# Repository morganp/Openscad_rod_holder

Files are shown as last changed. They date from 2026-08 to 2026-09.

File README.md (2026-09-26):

# openGrid Rod Holder

A deep, narrow pot that snaps onto an [openGrid](https://www.opengrid.world/)
board and keeps thin steel rod sorted by diameter. Built for 0.5 mm and 0.8 mm
hinge pin stock, but every dimension is parametric.

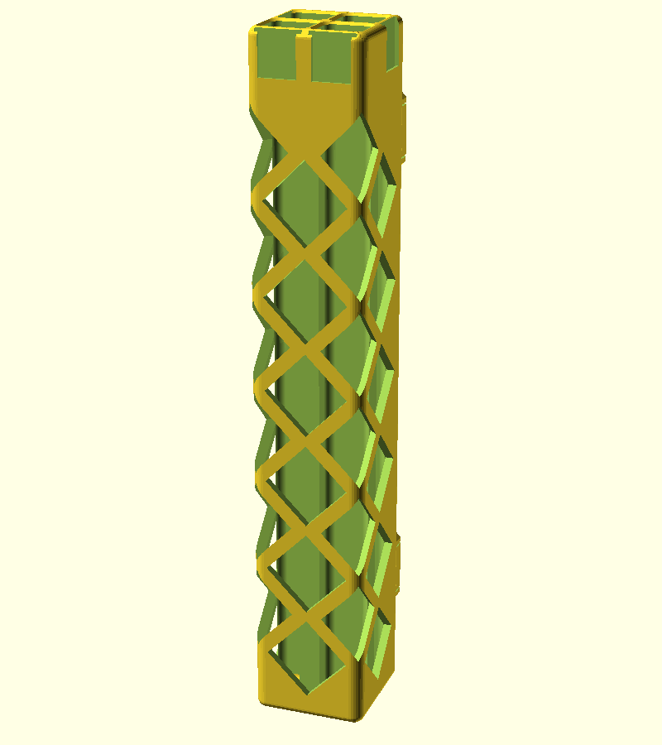
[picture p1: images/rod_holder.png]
Rod holder


- 1 grid cell square, 6 cells tall: 27.6 x 27.6 x 167.6 mm
- 4 compartments in a 2 x 2 grid, 11.0 x 10.5 mm, 165.6 mm deep, rounded inside
- A lattice of diamond windows up the outer walls, wrapping round the front
  corners, so short offcuts at the bottom can be seen
- Card label pocket for every compartment: front row on the front, back row on
  the sides
- Mounts on 2 snaps: one at the top, one at the bottom
- Tiles in both directions, so a wall of them lines up

Sized for 300 mm rod: the pot holds the bottom 166 mm and the rest stands
proud, so a full length rod is easy to grab.

Version 1 was 2 cells wide with 4 compartments in a single row. That is still
one setting away, see [v1 layout](#v1-layout).

## Requirements

The openGrid connector geometry lives in a separate library so other openGrid
projects can share it:

```sh
git clone https://github.com/morganp/openscad-opengrid.git \
  ~/Documents/OpenSCAD/libraries/opengrid
```

Then open `rod_holder.scad` in OpenSCAD.

Or open it in the browser with no install, library included:
[rod_holder.scad in the web OpenSCAD GUI](https://lizard-spock.co.uk/openscad-gui/?github=morganp/Openscad_rod_holder/rod_holder.scad).
The `// @github: morganp/openscad-opengrid` comment above the `include` tells
the web GUI where to fetch the library from; desktop OpenSCAD ignores it.

---

## Tiling

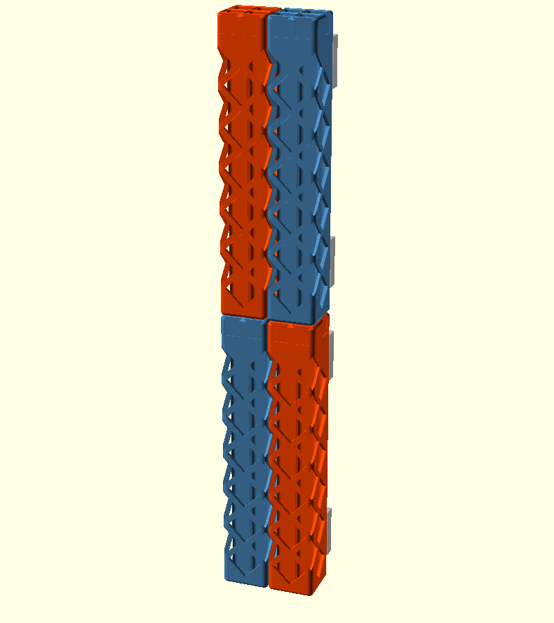
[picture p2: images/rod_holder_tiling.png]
Tiling


*Four holders in a 2 x 2 block, with the board cells their snaps sit in shown behind.*

The outer size is a whole number of grid cells **less `tile_clearance`**, taken
off the outside so the snaps stay put. At the defaults the holder is 27.6 x
167.6 mm and sits on a 28 x 168 mm footprint, which is 1 x 6 cells. It sits flush
beside any other holder or bin built to whole grid cells, and six-cell holders
stack flush above each other. Butt them up
against each other and every snap still lands on the 28 mm grid, with 0.4 mm of
air between neighbours so they do not rub.

Vertical tiling is what `height_mode` is for:

| `height_mode` | Height | Bore | Tiles vertically |
|---|---|---|---|
| `"grid"` (default) | Rounded up to a whole number of cells, 167.6 | 165.6 | Yes |
| `"exact"` | `bore_depth + floor_thickness`, 160 | 158 | No |

In `"grid"` mode `bore_depth` is a **minimum**. The height rounds up to the next
whole cell and the spare goes into the bore, so asking for 158 mm gets you
165.6 mm rather than 8 mm of dead plastic in the base. Use `"exact"` if you
want the bore depth you asked for and do not care about stacking.

---

## Layout

The pot's back wall *is* the mounting plate, so there is no separate bracket.
Snaps sit in the top and bottom rows only, one per column of grid cells.

Compartments form a grid: `compartments` across and `compartment_rows` front to
back. The depth comes from `pot_depth`:

| `pot_depth` | Depth | Compartments |
|---|---|---|
| `-1` (default) | Matches the width, 27.6 | Share the space behind the front wall, 10.5 deep each |
| `0` | `back_plate + rows * depth + dividers + wall` | `compartment_depth` deep, or square if that is 0 |
| any other value | That value | Share the space behind the front wall |

Snap centres have to land on the 28 mm grid and need 14 mm of clearance to any
plate edge, so the rows are pushed as far apart as the height allows and the
pair is centred:

```
snap_span = floor((pot_h - 28) / 28) * 28
snap_z0   = (pot_h - snap_span) / 2
```

At 167.6 mm tall that puts the rows 112 mm apart at z = 27.8 and z = 139.8.
Change `bore_depth` and they move to suit.

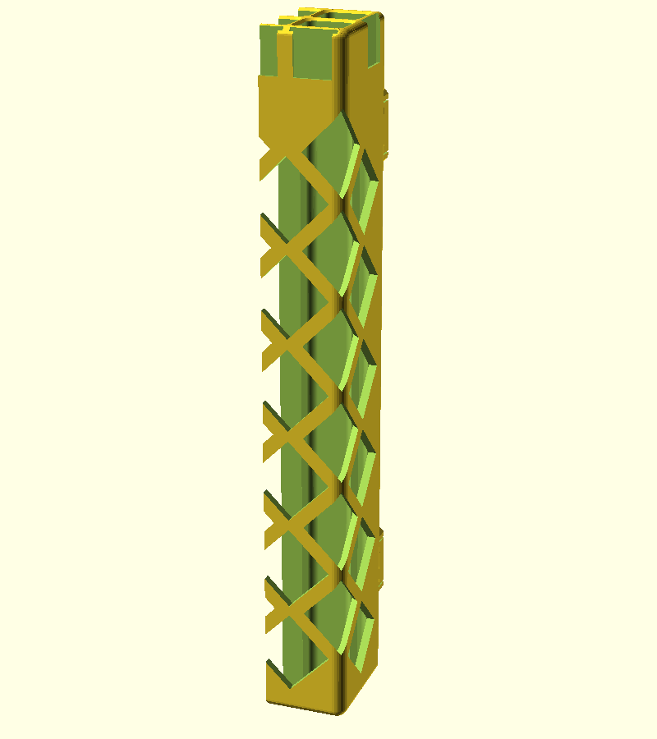
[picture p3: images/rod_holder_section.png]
Section


*Cut down the middle of the left column: the front and back bores, the floor, the diamond windows cut through the front wall, and the back plate the snaps hang off.*

---

## Windows

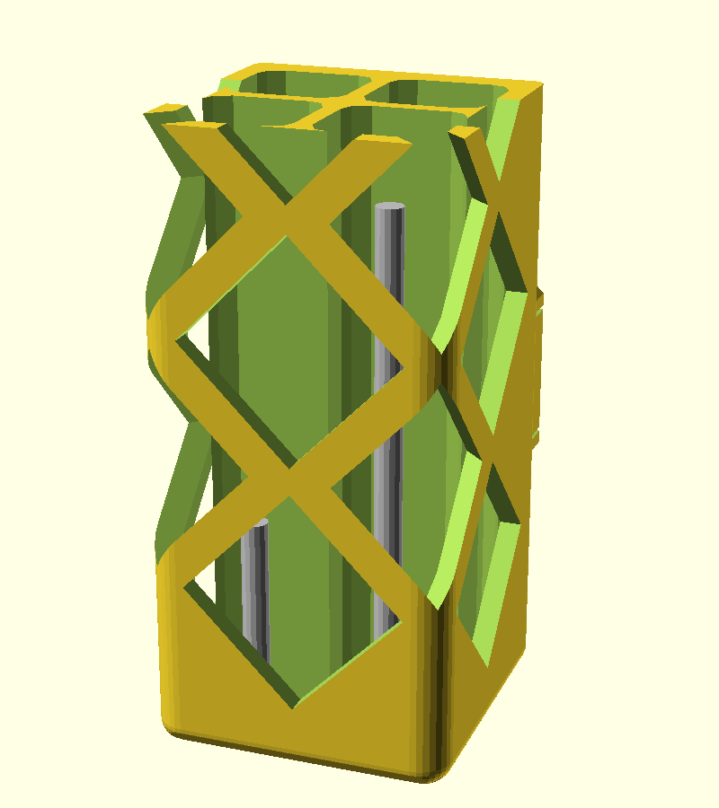
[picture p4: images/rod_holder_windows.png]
Windows


*The bottom of a holder from the front corner, with short offcuts standing in
the compartments. Offcuts drawn thicker than real rod so they show up.*

Rod gets used up from the top, so the pieces that get forgotten are the short
offcuts sitting at the bottom of a 166 mm deep bore. A lattice of diamond
windows runs up the outer walls so you can see them without tipping the holder
out.

The diamonds sit in alternating rows:

- **Row A** puts one diamond in the middle of each face. On the front it is
  centred on the grid cell, so on a 1 cell holder it spans both compartment
  columns. On each side it is centred between the back plate and the front
  wall, so it spans both compartment rows.
- **Row B**, half a pitch higher, puts a diamond on each front vertical edge.
  It wraps round the corner, half on the front and half on the side, and opens
  up the front corner of the compartment behind it. It is cut as one prism
  running in along the corner's 45 degree bisector, so the outline runs
  continuously over the rounded edge and each face still shows a 45 degree
  half diamond. Cutting a half diamond straight into each face instead leaves
  pinched nubs where the webs cross the rounded corner. On holders wider than one
  cell, row B also has a full diamond on the front at every cell boundary.
- The back edges and the back plate stay solid. That is where the snaps are.

At the defaults the diamonds are 20.2 mm across, 45 degree squares, with a
2.4 mm web between neighbours. There are 12 rows, 22.6 mm apart for rows of
the same kind: 6 A rows and 6 B rows, from 6 mm above the bottom to just below
the card pockets. So each side face has 6 full diamonds and 6 half diamonds
round the corner, and the front has 6 full diamonds and 12 corner halves.

`diamond_size = 0` makes the diamonds as big as the faces allow, and a larger
value is clamped to that with a note in the console. The spacing follows from
the size and `diamond_web`: rows of the same kind are spaced so their tips are
a web apart, and an A and a B diamond are a web apart across the diagonal.

The windows only cut the outer walls. Where a row A diamond crosses the end of
a divider it takes the wall off the end of the divider, but the divider stays
joined to the back plate, to the other divider, and to the outer wall at every
row B height, so the part is still one solid. At the wrapped corners the cut
also clears the rounded inside corner of the compartment, which would
otherwise be left as a thin free standing sliver in the middle of the opening.

**Why the windows start above the floor.** The lowest diamond tip is
`window_start` (4 mm) above the floor. A rod standing in a compartment rests its
bottom end on the floor behind solid wall, so to lean out of a window it would
have to be lifted over that band first. Gravity keeps it seated, and a rod
leaning against a window can only poke its *top* end out, which slides it
upwards, not out. Offcuts shorter than the compartment is wide can lie flat on
the floor, below the windows. The holder can still lose short pieces if it is
knocked off the wall or turned upside down.

**Tiling hides the side windows.** Holders butted up to each other cover each
other's side faces. The front diamonds and the front halves of the corner
diamonds still show all four compartments' front corners; the back row is only
fully visible from a free side (the end of a row), a one cell gap, or the top.

**Printing.** Front face down, the front diamonds are holes in the first
layers, and every edge of the side diamonds runs at 45 degrees, so there are no
bridges and no support.

`window_style = "slot"` gives the earlier ladder of narrow slots, one column per
compartment, and `"none"` leaves the walls solid.

---

## Rounding

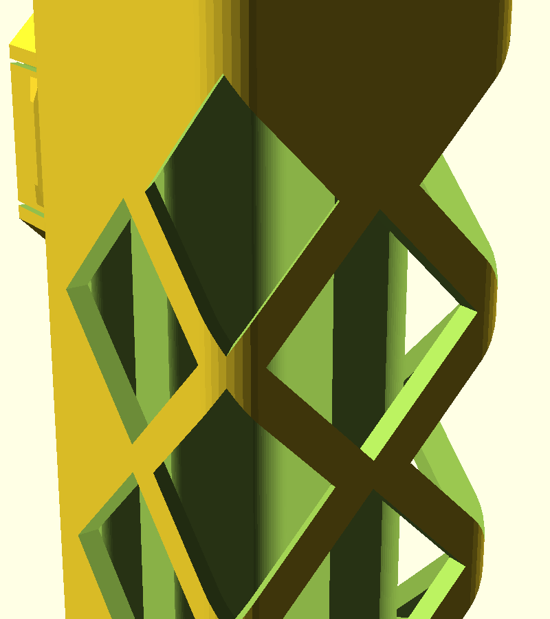
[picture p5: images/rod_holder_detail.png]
Detail


*The top of the pot: rounded outer edges, the lead-in at each mouth, front card
pockets for the front row, a side pocket for the back row, and the top of the
diamond lattice with a corner diamond wrapping the front edge.*

Outside, the two front vertical edges are rounded by `outer_round`, the top and
bottom edges by `end_round`. Inside, the compartment corners are rounded by
`inner_round` and there is a fillet where the walls meet the floor.

Two edges cannot simply be rounded, for reasons worth knowing before you change
the values:

**The back edges.** Rounding the back face perimeter eats into the flat area the
snaps root into. Each snap reaches 12.4 mm from its centre and a one cell pot
is 13.8 mm from centre to side, so anything above 1.4 mm would undercut them. `back_round` defaults
to 1.2 and is checked by an assert.

**The front face perimeter.** The front face is the bed when printing. A fillet
tangent to the bed leaves the first layers as a near-horizontal overhang, which
prints badly. So the rounding is cut back to 45 degrees where it runs into that
face, by `front_chamfer`. This catches the side edges and the top and bottom
edges in one operation. Set `front_chamfer = 0` for an unbroken round, and print
with support.

The mouth lead-in grows every compartment sideways and backwards, so two
neighbours eat into the divider between them from both sides. It is clamped to
leave at least 0.4 mm on top of each divider, which means the effective lead-in
can be smaller than `mouth_chamfer` asks for. It never grows into an outer wall
that carries a card pocket.

---

## Card labels

Every compartment gets a pocket in an outer wall that holds a slip of card
behind a window. Cards drop in from the top of the pot and pull straight back
out, so relabelling means writing a new slip rather than reprinting the holder.

- Front row compartments are labelled on the front face.
- Rows behind that are labelled on the side wall they touch: the left back
  compartment on the left side, the right one on the right. A single column
  uses the left side.
- A compartment that touches no outer wall (a middle column of three or more,
  behind the front row) cannot be labelled, and OpenSCAD echoes a note.

At the defaults the front cards are 11.0 x 12 mm with a 9.0 x 11 mm window, the
side cards 10.5 x 12 mm with an 8.5 x 11 mm window, all in 0.7 mm slots. Cut a
strip of 300 gsm card, or fold ordinary paper double.

Set `label_mode = "engraved"` to cut fixed text into the same faces instead, or
`"none"` to leave it plain. `labels` runs front row left to right as mounted,
then the next row back, left to right.

---

## Parameters

### openGrid

| Parameter | Default | Description |
|---|---|---|
| `grid_cols` | `1` | How many grid cells wide |
| `lite_board` | `false` | `true` for a 4.0 mm Lite board, `false` for a 6.8 mm Full board |
| `snap_clearance` | `0` | Raise to 0.05 to 0.1 if the snaps print tight |
| `tile_clearance` | `0.4` | Gap left between neighbouring holders. Taken off the outside, the snaps stay on the grid |
| `height_mode` | `"grid"` | `"grid"` rounds the height to whole cells so holders tile vertically. `"exact"` gives exactly `bore_depth + floor_thickness` |

### Pot

| Parameter | Default | Description |
|---|---|---|
| `bore_depth` | `158` | Usable compartment depth. A minimum in `"grid"` mode |
| `compartments` | `2` | Number of compartments across the width |
| `compartment_rows` | `2` | Number of compartment rows, front to back |
| `pot_depth` | `-1` | `-1` matches the width, `0` sizes from `compartment_depth`, any other value is the depth |
| `wall` | `2.0` | Front and side wall thickness |
| `divider` | `1.6` | Thickness of the walls between compartments |
| `back_plate` | `3.0` | Back plate thickness, this is what the snaps hang off |
| `floor_thickness` | `2.0` | Material under the compartments |
| `compartment_depth` | `0` | Front to back size, used only when `pot_depth = 0`. `0` makes the compartments square |
| `mouth_chamfer` | `1.0` | Lead-in at the mouth. Never opens into a wall with a card pocket. Clamped so it cannot eat the divider tops away |

Compartment width is whatever is left over:

```
comp_w = (grid_cols * 28 - tile_clearance - 2 * wall
          - (compartments - 1) * divider) / compartments
```

which gives 11.0 mm at the defaults, and the depth is shared the same way
behind the front wall, 10.5 mm.

### Windows

| Parameter | Default | Description |
|---|---|---|
| `window_style` | `"diamond"` | `"diamond"` lattice, `"slot"` ladders, or `"none"` |
| `window_sides` | `true` | Windows in the side walls |
| `window_front` | `true` | Windows in the front wall |
| `window_start` | `4` | Solid band above the floor before the first window |
| `window_zone` | `0` | Height of the windowed region above `window_start`. `0` runs up to just below the labels |
| `diamond_size` | `0` | Diamond diagonal. `0` is as big as the faces allow, larger values are clamped to that |
| `diamond_web` | `2.4` | Narrowest web between diamonds, and between diamonds and the labels. At least 1.6 |
| `diamond_corners` | `true` | Diamonds wrapped round the two front vertical edges |
| `window_width` | `4` | Slot style only. Slot width, clamped to the flat part of the compartment wall |
| `window_height` | `10` | Slot style only. Height of each slot, and the bridge over it when printing |
| `window_bar` | `4` | Slot style only. Solid rung between slots |

### Rounding

| Parameter | Default | Description |
|---|---|---|
| `outer_round` | `3.0` | Radius on the two front vertical edges, the ones you grip |
| `back_round` | `1.2` | Radius on the two back vertical edges. Capped by the snap footprint, see above |
| `end_round` | `2.0` | Radius on the top and bottom outer edges |
| `front_chamfer` | `1.6` | 45 degree relief where the rounding meets the front face, so it prints off the bed. `0` gives an unbroken round |
| `inner_round` | `2.0` | Radius on the inside vertical corners of each compartment |
| `floor_round` | `2.0` | Radius where the compartment walls meet the floor |

### Labels

| Parameter | Default | Description |
|---|---|---|
| `label_mode` | `"card"` | `"card"`, `"engraved"` or `"none"` |
| `card_height` | `12` | Height of the card pocket. Width follows the compartment |
| `card_thickness` | `0.7` | Thickness of card the slot takes |
| `card_lip` | `0.6` | Front frame that stops the card falling out |
| `card_lip_margin` | `1.0` | How far that frame overlaps the card at the sides and bottom |
| `card_side_gap` | `0.8` | Gap each side of the card. Twice this is the rib between neighbouring pockets, so keep it near half the divider thickness |
| `labels` | `["0.5", "0.8", "1.0", "1.5"]` | Engraved mode only. Front row left to right as mounted, then the next row back |
| `label_size` | `5` | Engraved glyph height |
| `label_depth` | `0.6` | Engraving depth |
| `label_inset` | `10` | Engraved mode only, distance from the top down to the middle of the text |

### Output

| Parameter | Default | Description |
|---|---|---|
| `layout` | `"assembled"` | `"assembled"` shows it as mounted, `"print"` lays it out for the bed |
| `show_board` | `false` | Draw the board cells behind it, preview only |

---

## Printing

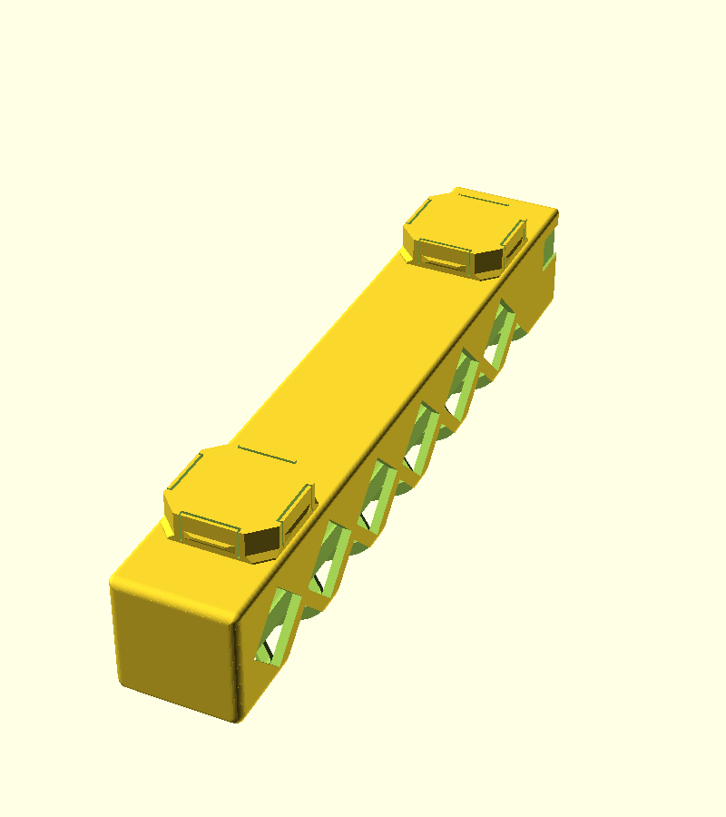
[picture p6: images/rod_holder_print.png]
Print layout


Set `layout = "print"`. That lays the pot **front face down** with the snaps
pointing up, which is the orientation this part wants:

- every snap overhang is 45 degrees or shallower, so no support is needed
- the front card pocket frames are on the bed and come out crisp, and the roof
  of each pocket is a short flat bridge between two edges
- the side diamonds have 45 degree edges all round, so they need no bridges
- the side card pockets are holes in vertical walls, each topped by a 10 to
  11 mm flat bridge
- the compartment bores run horizontally and need no bridging

Following the [openGrid printing guide](https://www.opengrid.world/guides/printing/):

- 0.4 mm nozzle, 0.2 mm layer height
- PLA or PETG, not flexibles
- At least 3 perimeters, this part hangs off a wall
- 15% infill or more
- Do not use a draft or fast profile, it will ruin the snap tolerances

Bed needs to fit 167.6 x 27.6 mm, 34.4 mm tall with the snaps. About 48 cm3 of
material at the defaults.

**Print one snap first.** Run the library's tile and snap examples and check the
fit by hand before committing to a 168 mm part.

---

## Verifying the fit

`mountfit_check.scad` intersects the finished holder with the board cells its
snaps sit in. A snap that fits has zero overlap with the board, so exporting
that intersection should give a zero volume solid:

```sh
openscad --export-format=binstl -o mountfit.stl mountfit_check.scad
```

This currently comes out at 0 mm3, so the snaps clear their cells everywhere at
rest.

---

## v1 layout

The version 1 holder, 2 cells wide with 4 compartments in one row and no
windows, is these settings:

```sh
openscad -D grid_cols=2 -D compartments=4 -D compartment_rows=1 -D pot_depth=0 \
         -D bore_depth=150 -D window_style=\"none\" \
         -o rod_holder_v1.stl rod_holder.scad
```

That produces the same solid as v1.2.0, checked by volume (80.5 cm3) and
triangle count. Leave the windows on to get a v1 shape with windows.

---

## Files

```
rod_holder.scad        -- the model
mountfit_check.scad    -- snap-to-board interference check
section_preview.scad   -- cutaway used for the README image
tiling_preview.scad    -- 2 x 2 block used for the README image
windows_preview.scad   -- corner view with offcuts, used for the README image
images/                -- rendered previews
```

## Credit

openGrid is a wall and desk mounting system by **David D**, CC BY 4.0:
<https://www.printables.com/model/1214361-opengrid-walldesk-mounting-framework-and-ecosystem>

Connector geometry comes from
[openscad-opengrid](https://github.com/morganp/openscad-opengrid).

## Versioning

[Semantic Versioning 2.0.0](https://semver.org). See [CHANGELOG.md](CHANGELOG.md).

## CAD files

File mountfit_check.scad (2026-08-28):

// mountfit_check.scad -- verification, not part of the model.
// A snap that fits its cell has zero overlap with the board, so exporting this
// intersection should come out as an empty or zero volume solid.
use <rod_holder.scad>

intersection() {
    board_cells();
    rod_holder();
}

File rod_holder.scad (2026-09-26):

/*
 * rod_holder.scad -- openGrid mounted pot for thin steel rods
 *
 * A deep, narrow pot that snaps onto an openGrid board and keeps hinge pin
 * stock sorted by diameter. Sized around 0.5 mm and 0.8 mm steel rod, but every
 * dimension is parametric.
 *
 * Version 2.0.0: one grid cell square, four compartments in a 2 x 2 grid, and
 * a lattice of diamond windows in the outer walls so short offcuts at the
 * bottom can be seen.
 *
 * Requires: https://github.com/morganp/openscad-opengrid
 *   git clone .../openscad-opengrid ~/Documents/OpenSCAD/libraries/opengrid
 *
 * Coordinates: the openGrid board face is the y = 0 plane. Snaps reach back into
 * the board at y < 0, the pot stands off the wall at y > 0, and z = 0 is the
 * bottom of the pot.
 *
 * Holders tile. Width is a whole number of grid cells less tile_clearance, and
 * with height_mode = "grid" the height is too, so a row or a column of these
 * sits side by side on the board with every snap still on the 28 mm grid.
 */

// @github: morganp/openscad-opengrid
include <opengrid/opengrid.scad>

/* [openGrid] */
// how many grid cells wide the holder is
grid_cols = 1;          // [1:6]
// true for a 4.0 mm Lite board, false for a 6.8 mm Full board
lite_board = false;
// raise if the snaps print tight
snap_clearance = 0;     // [0:0.01:0.2]
// gap left between neighbouring holders so they do not rub. Taken off the
// outside of the pot, the snaps stay on the grid
tile_clearance = 0.4;   // [0:0.1:2]
// exact makes the pot bore_depth + floor tall. grid rounds the height up to a
// whole number of cells so holders also tile vertically, deepening the bore
height_mode = "grid";   // [exact, grid]

/* [Pot] */
// usable depth of each rod compartment. With height_mode = "grid" this is a
// minimum and the bore gets deeper to reach the next whole cell
bore_depth = 158;       // [20:1:300]
// number of compartments across the width
compartments = 2;       // [1:8]
// number of compartment rows, front to back
compartment_rows = 2;   // [1:4]
// overall depth from the board face to the front face. -1 matches the width,
// so a 1 cell holder is square. 0 sizes it from compartment_depth instead
pot_depth = -1;
// front and side wall thickness
wall = 2.0;
// thickness of the walls between compartments
divider = 1.6;
// back plate thickness, this is what the snaps hang off
back_plate = 3.0;
// thickness under the compartments
floor_thickness = 2.0;
// compartment size front to back, used only when pot_depth = 0. 0 makes them
// square
compartment_depth = 0;
// Lead in at the mouth of each compartment. Clamped so it cannot eat the tops
// of the dividers away, so the effective value may be smaller than this
mouth_chamfer = 1.0;

/* [Windows] */
// diamond cuts a lattice of diamonds through the outer walls, slot a ladder of
// narrow slots per compartment, none leaves the walls solid
window_style = "diamond";  // [diamond, slot, none]
// windows in the side walls
window_sides = true;
// windows in the front wall
window_front = true;
// solid band above the floor before the first window. Keeps the bottom end of
// a standing rod behind a wall, so it cannot slide out of a window
window_start = 4;
// height of the windowed region above window_start. 0 runs the windows up to
// just below the labels
window_zone = 0;

// -- diamond style --
// Diagonal of each diamond. 0 makes them as big as the faces allow, so the
// diamond on a face spans every compartment column behind it. Clamped to that
// size if set larger
diamond_size = 0;
// narrowest solid web left between neighbouring diamonds, and between the
// diamonds and the back plate or labels
diamond_web = 2.4;
// diamonds centred on the two front vertical edges, wrapping round the corner
// so half shows on the front and half on the side
diamond_corners = true;

// -- slot style --
// slot width. Clamped to the flat part of the compartment wall
window_width = 4;
// height of each slot
window_height = 10;
// solid rung left between slots
window_bar = 4;

/* [Rounding] */
// radius on the two front vertical edges, the ones you actually grip
outer_round = 3.0;
// radius on the two back vertical edges. Kept small: the back face has to stay
// flat out to the edge of the snaps, which reach 12.4 mm from each snap centre
back_round = 1.2;
// radius on the top and bottom outer edges
end_round = 2.0;
// 45 degree relief around the front face. The front face is the bed when
// printing, and a fillet tangent to the bed starts as a near horizontal
// overhang, so the rounding is cut back to 45 degrees where it meets that face.
// Set to 0 for an unbroken round, and print with support
front_chamfer = 1.6;
// radius on the inside vertical corners of each compartment
inner_round = 2.0;
// radius where the compartment walls meet the floor
floor_round = 2.0;

/* [Labels] */
// card holds a slip of card behind a window, engraved cuts the text into the
// outer face, none leaves it plain. Front row labels go on the front face,
// rows behind it are labelled on the side wall they touch
label_mode = "card";    // [card, engraved, none]

// -- card mode --
// height of the card pocket. Width follows the compartment
card_height = 12;
// thickness of card the pocket takes. 0.7 suits folded paper or 300 gsm card
card_thickness = 0.7;
// front frame that stops the card falling out
card_lip = 0.6;
// how far that frame overlaps the card at the sides and bottom
card_lip_margin = 1.0;
// gap each side of the card. Twice this is the rib left between neighbouring
// pockets, so do not take it below about half the divider thickness
card_side_gap = 0.8;

// -- engraved mode --
// one label per compartment, "" for none. Front row left to right as mounted,
// then the next row back, left to right. Extras are ignored
labels = ["0.5", "0.8", "1.0", "1.5"];
label_size = 5;
label_depth = 0.6;
// distance from the top of the pot down to the middle of the label
label_inset = 10;

/* [Output] */
// assembled shows it as mounted, print lays it front face down on the bed
layout = "assembled";   // [assembled, print]
// draw a piece of board behind it, preview only
show_board = false;

/* [Hidden] */
$fn = 64;
EPS = 0.01;

// ---------------------------------------------------------------------------
// Derived dimensions
// ---------------------------------------------------------------------------

// Outer size is a whole number of cells less the tiling gap, so neighbouring
// holders leave tile_clearance between them while their snaps stay 28 mm apart.
pot_w    = og_span(grid_cols) - tile_clearance;         // 27.6 for 1 cell
grid_h   = ceil((bore_depth + floor_thickness) / OG_PITCH) * OG_PITCH;
pot_h    = height_mode == "grid" ? grid_h - tile_clearance
                                 : bore_depth + floor_thickness;
bore     = pot_h - floor_thickness;             // 165.6 in grid mode
inner_w  = pot_w - 2 * wall;
comp_w   = (inner_w - (compartments - 1) * divider) / compartments;

// Depth either comes from the compartments (pot_depth = 0) or is fixed and the
// compartments share out whatever is left behind the front wall.
rows_gaps = (compartment_rows - 1) * divider;
pot_d    = pot_depth < 0 ? pot_w
         : pot_depth > 0 ? pot_depth
         : back_plate + compartment_rows * (compartment_depth > 0 ? compartment_depth : comp_w)
           + rows_gaps + wall;
comp_d   = (pot_d - back_plate - wall - rows_gaps) / compartment_rows;

// The mouth lead in grows every compartment sideways, so two neighbours eat
// into the divider between them from both sides. Clamp it so the top of a
// divider keeps at least divider_top_min of material rather than coming to a
// knife edge, or vanishing entirely when 2 * mouth_chamfer exceeds divider.
divider_top_min = 0.4;
mouth = compartments > 1 || compartment_rows > 1
        ? min(mouth_chamfer, max(0, (divider - divider_top_min) / 2))
        : mouth_chamfer;

// Snap rows sit on the 28 mm grid and need 14 mm of clearance to a plate edge,
// so push them as far apart as the height allows and centre the pair.
snap_span = floor((pot_h - OG_PITCH) / OG_PITCH) * OG_PITCH;
snap_z0   = (pot_h - snap_span) / 2;
snap_zs   = snap_span > 0 ? [snap_z0, pot_h - snap_z0] : [pot_h / 2];
snap_xs   = [ for (c = [0 : grid_cols - 1]) (c - (grid_cols - 1) / 2) * OG_PITCH ];
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

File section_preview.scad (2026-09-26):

// section_preview.scad -- cutaway used for the README image.
// Not part of the model, it just slices rod_holder() down the middle of the
// left hand column so the front and back bores, the floor, the diamond windows and the
// snap seating are all visible at once.
use <rod_holder.scad>
// @github: morganp/openscad-opengrid
include <opengrid/opengrid.scad>

difference() {
    rod_holder();
    // remove everything to the viewer's left of the middle of that column
    translate([6.3, -10, -1]) cube([20, 50, 200]);
}

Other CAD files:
tiling_preview.scad
windows_preview.scad

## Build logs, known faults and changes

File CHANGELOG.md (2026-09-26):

# Changelog

All notable changes to this project. Versions follow
[Semantic Versioning 2.0.0](https://semver.org).

## 2.0.1 - 2026-09-26

### Fixed
- `// @github: morganp/openscad-opengrid` tag above each `include` of the
  openGrid library, so the web OpenSCAD GUI deep link
  (<https://lizard-spock.co.uk/openscad-gui/?github=morganp/Openscad_rod_holder/rod_holder.scad>)
  fetches the library automatically. Desktop OpenSCAD sees a comment only.

## 2.0.0 - 2026-09-26

### Changed (breaking defaults)
- Default holder is now 1 grid cell square (27.6 x 27.6 x 167.6 mm) with four
  compartments in a 2 x 2 grid, 11.0 x 10.5 mm. The v1 holder is still available
  with `grid_cols = 2`, `compartments = 4`, `compartment_rows = 1`,
  `pot_depth = 0`, `bore_depth = 150` and the windows turned off, and produces
  the same solid as 1.2.0.
- `bore_depth` default 150 -> 158. In grid height mode the pot is still 6 cells,
  167.6 mm.
- The mouth lead-in no longer opens into an outer wall that carries a card
  pocket.

### Added
- `compartment_rows` and `pot_depth` (`-1` matches the width, `0` sizes from
  `compartment_depth`).
- Diamond lattice windows in the outer walls (`window_style = "diamond"`,
  default): one diamond per face in alternating rows with diamonds wrapped round
  the two front vertical edges (cut along the corner bisector so the outline is
  continuous over the rounded edge), 45 degree edges so the side holes print without
  bridges. `diamond_size`, `diamond_web`, `diamond_corners`.
- `window_style = "slot"` keeps a ladder of narrow slots per compartment
  (`window_width`, `window_height`, `window_bar`). Shared window settings:
  `window_sides`, `window_front`, `window_start`, `window_zone`.
- Card pockets and engraved labels on the side walls for compartments behind
  the front row.
- `windows_preview.scad` and `images/rod_holder_windows.png`.

## 1.2.0 - 2026-08-28
- Rounded outer edges and compartment insides, 45 degree relief on the front
  face for printing.

## 1.1.0 - 2026-08-28
- Tiling on both axes (`tile_clearance`, `height_mode`) and card label pockets.

## 1.0.0 - 2026-08-28
- openGrid rod holder, 4 compartments, 150 mm deep.

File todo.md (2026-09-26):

# Rod holder todo

## Next
- [ ] Print one bare snap plus a single-cell test tile from the `opengrid`
      library, check the snap fit by hand before printing the full 168 mm pot.
- [ ] Print the holder with `layout = "print"` and confirm no support is needed.
- [ ] Check 0.5 mm rod is actually retrievable from a 165.6 mm deep, 11.0 x
      10.5 mm compartment. If it is fiddly, add a front finger cutout as an option.
- [ ] Window rod retention: load short offcuts (10 to 60 mm) of 0.5 and 0.8 mm
      rod, tap and tilt the mounted holder, and check nothing escapes through
      the 20 mm diamonds, especially the wrapped corners. If it does, raise
      `window_start`, shrink `diamond_size`, or use `window_style = "slot"`.
- [ ] Check the diamond lattice prints cleanly front face down: 2.4 mm webs,
      45 degree side edges, and the wrapped corners. Check the pot is stiff
      enough on the wall with this much wall cut away (about 48 cm3 left of 59).
- [ ] Check the side card pockets print cleanly (10 to 11 mm bridges in
      vertical walls).
- [ ] Check the card pocket takes whatever card is to hand. card_thickness is
      0.7, which suits 300 gsm or folded paper. Measure before printing four.
- [ ] Print two holders and confirm they actually sit side by side on the board
      with the 0.4 mm tile_clearance.
- [ ] Decide whether back row visibility matters when holders are tiled (side
      windows are hidden by neighbours). Option: windows through the row
      divider as well, lined up with the front windows.

## Open questions
- [ ] Download `openGrid Tile Dimensions.pdf` from the Printables model (needs a
      Printables login) and check the library constants against David D's own
      drawing. The numbers currently come from agreement between three
      independent community implementations, which matched exactly, but the
      official drawing has not been read directly.

## Ideas
- [ ] Lid or rubber bung so rods cannot fall out if the holder is knocked.
- [ ] Variant with round graded bores instead of square compartments.
- [x] 1 cell square, 2 x 2 compartments, diamond lattice windows (v2.0.0)

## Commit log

2026-08-28 feat: openGrid mounted rod holder
    Parametric pot for storing thin steel hinge pin rod, 2 grid cells wide
    with 4 square compartments 150 mm deep.
    The pot's back wall doubles as the mounting plate, with snaps in the top
    and bottom rows only. Row spacing is derived rather than fixed: the rows
    are pushed as far apart as the grid allows while keeping 14 mm of edge
    clearance, so changing bore_depth keeps the snaps aligned to the board.
    Connector geometry comes from the openscad-opengrid library rather than
    being duplicated here.
    mountfit_check.scad intersects the finished holder with the board cells
    its snaps sit in; that comes out at 0 mm3, confirming the snaps clear
    their cells at rest.
    Co-A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
    [mountfit_check.scad, rod_holder.scad, section_preview.scad]
2026-08-28 feat: tile in both axes and hold card labels
    The holder was exactly 56 mm wide, so neighbours butted with zero
    clearance and would rub once print tolerance is taken into account. It
    was also 152 mm tall, which is not a whole number of cells, so stacking
    two put the upper one's snaps off the grid.
    Outer size is now a whole number of cells less tile_clearance, taken off
    the outside so the snaps stay where they were. height_mode = "grid"
    rounds the height up to the next whole cell and puts the spare into the
    bore rather than the floor, making bore_depth a minimum. Defaults now
    give 55.6 x 167.6 mm on a 2 x 6 cell footprint.
    Fixed engraved sizes are replaced by a card pocket per compartment: a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
    [rod_holder.scad, tiling_preview.scad]
2026-08-28 feat: round the outer edges and the compartment insides
    Adds a rounded_extrude helper that lofts a 2D profile through a quarter
    circle of inset values, used for both the outside of the pot and the
    compartment voids, where an inset void leaves a concave fillet in the
    solid.
    Outside: the front vertical edges, and the top and bottom edges, are
    rounded. Inside: the compartment corners are rounded and the walls meet
    the floor on a fillet.
    Two edges could not simply be rounded.
    The back edges are limited by the snaps. The snaps reach 26.4 mm from the
    centre against a 27.8 mm half width, so any radius over 1.4 mm undercuts
    their roots. back_round defaults to 1.2 and an assert enforces the limit.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
    [rod_holder.scad]
2026-09-26 feat!: one cell square holder with 2 x 2 compartments and diamond windows
    Default holder is now 1 grid cell square (27.6 x 27.6 x 167.6 mm) with
    four 11.0 x 10.5 mm compartments in a 2 x 2 grid, for 300 mm hinge pin
    rod.
    - compartment_rows and pot_depth generalise the compartments to a grid
    - a lattice of 45 degree diamond windows in the outer walls shows short
    offcuts at the bottom: one diamond per face in alternating rows, with
    diamonds wrapped round the two front vertical edges. The lattice starts
    4 mm above the floor so a standing rod cannot slide out
    - window_style = "slot" keeps a ladder of narrow slots per compartment
    - back row compartments get card pockets or engraved labels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
    [rod_holder.scad, section_preview.scad, tiling_preview.scad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]
2026-09-26 fix: tag openGrid library include for the web GUI
    Add a // @github: morganp/openscad-opengrid comment above each include
    of the library so the OpenSCAD GUI deep link fetches it automatically.
    [rod_holder.scad, section_preview.scad, tiling_preview.scad]
